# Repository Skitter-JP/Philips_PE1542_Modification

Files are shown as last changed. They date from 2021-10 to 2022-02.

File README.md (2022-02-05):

# Philips PE1542 Modification

This project provides you a 3D model and video with instructions on how to replace the analog meters with digital meters on a Philips PE1542 bench power supply.

The video is available by clicking on the image below.

VIDEO (https://www.youtube.com/embed/GQAOcTNk6Aw)

In the video I have used meters with 3 decimals precision but, the sampling rate on these were incredibly slow. I later switched to meters with 2 decimals precision which were faster. I suspect that these meters contain integrating ADCs, hence the slow updating times.

Click [here](https://www.ebay.com/itm/114450600499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) to view/purchase the meters on eBay.

The mains transformer has 3 outputs. 2 of them are outputting around 30 [Vpp], the last one is at 12[Vpp].

The maximum operating voltage for the replacement meters are 20 [V], this means that for 2 outputs with 30[Vpp] some voltage drop is needed. This was achieved by implementing a [Zener Voltage Regulator](https://www.electronics-tutorials.ws/diode/diode_7.html) circuit after the rectifying capacitor on the two outputs.

The project contains the following folders
1. **3D Model:** An STL file which contains a mount that will fit into the space where the original meters were placed.
2. **Images**: Pictures showcasing the final results of the modification (images might be a bit big to view via GitHub, best to download them)

## 3D Model

The 3D model seen in Google SketchUp

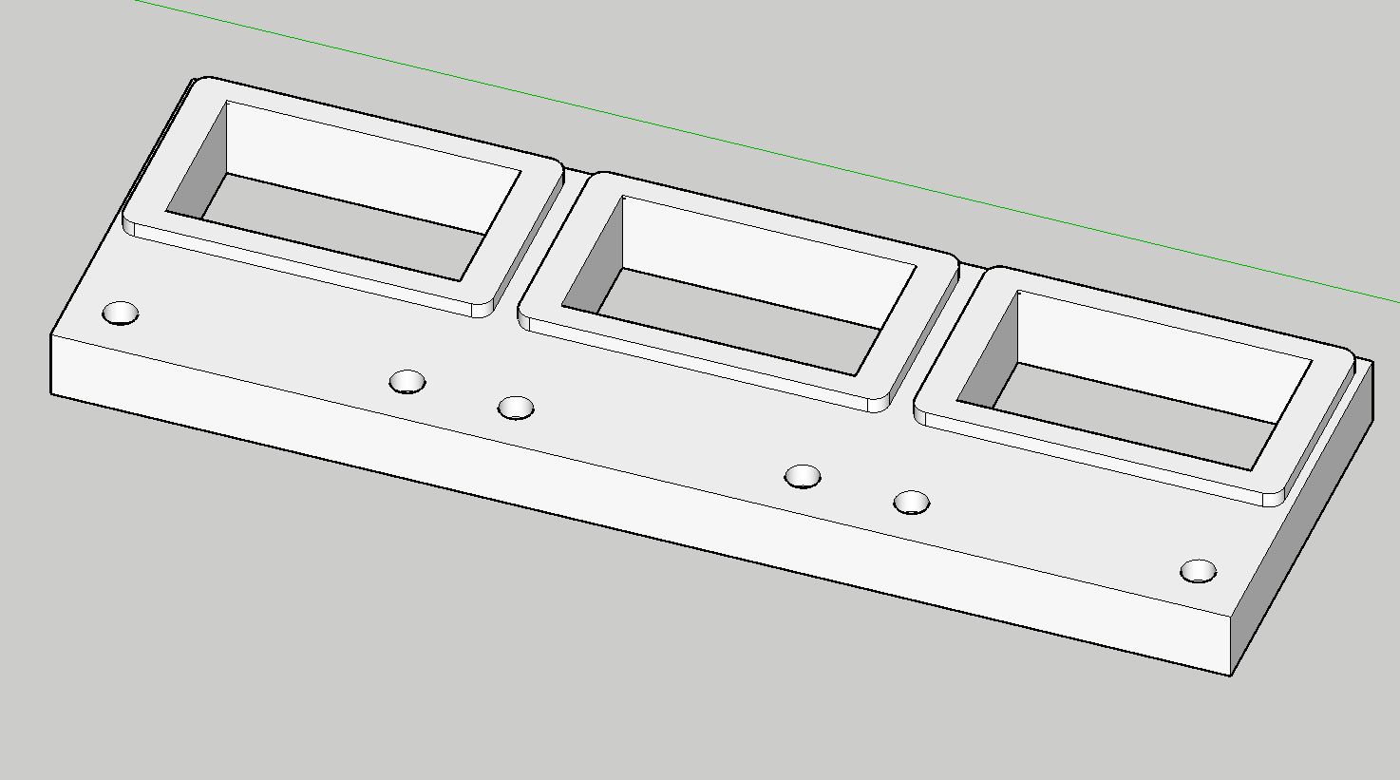
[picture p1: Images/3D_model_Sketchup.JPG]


## 3D Print

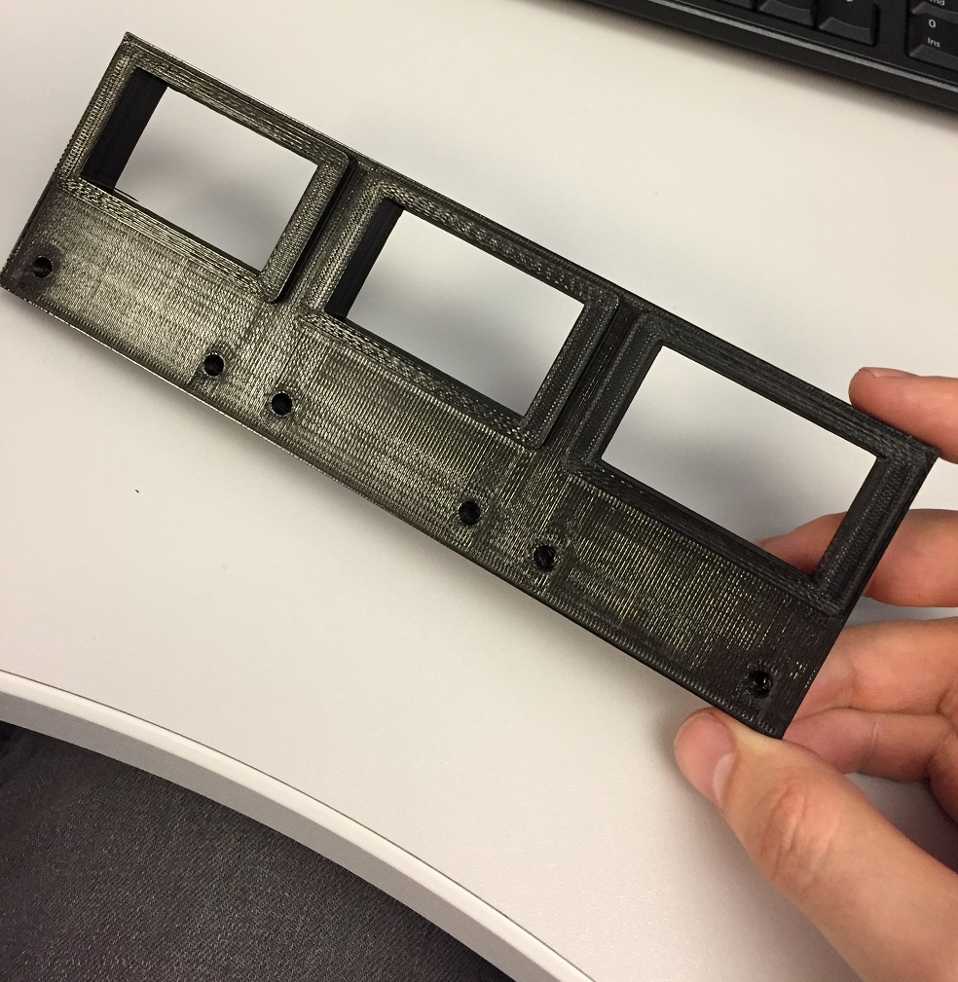
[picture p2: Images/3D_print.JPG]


## Test fitting the 3D print to the faceplate

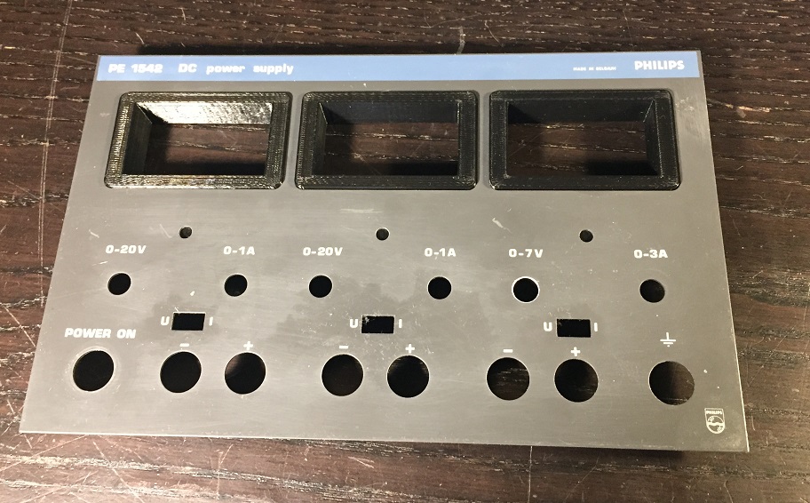
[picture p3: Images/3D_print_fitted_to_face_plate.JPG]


## Test fitting the 3D print into the enclosure

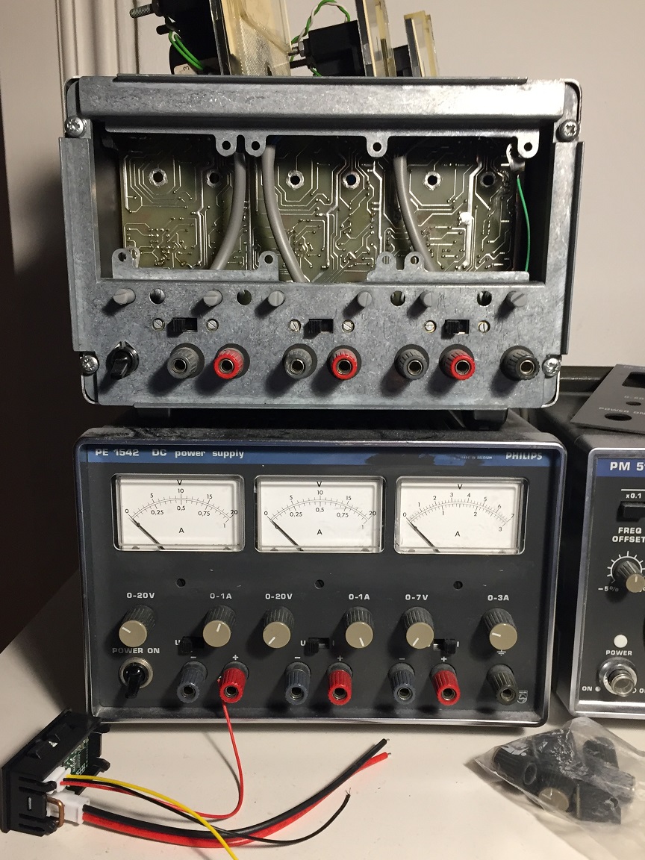
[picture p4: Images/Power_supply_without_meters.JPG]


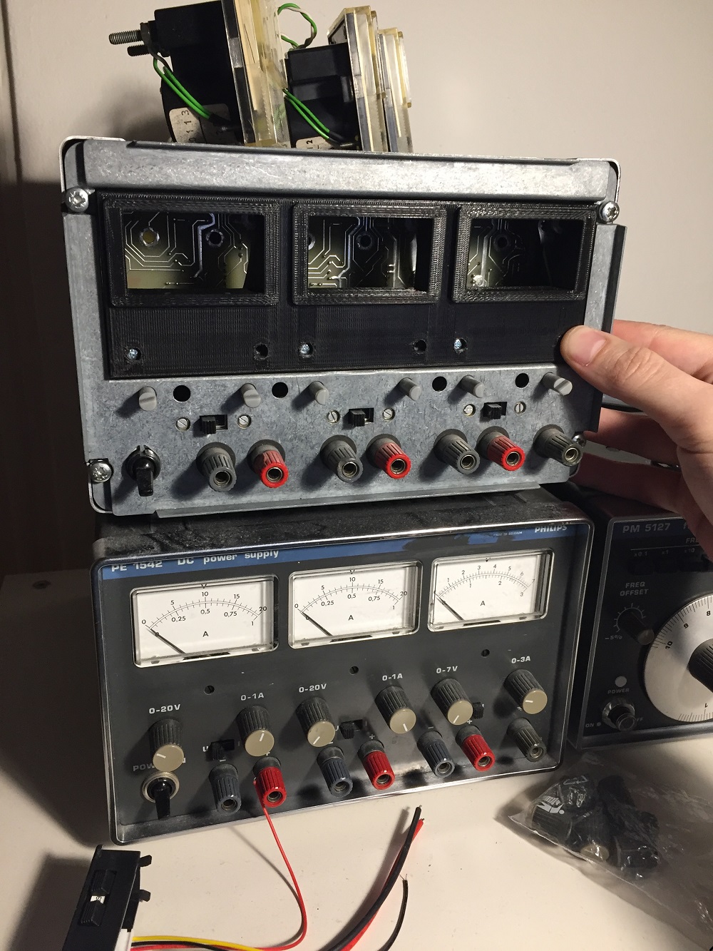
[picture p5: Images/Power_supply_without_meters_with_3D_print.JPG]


## Fitting the Digital Meters to the 3D print

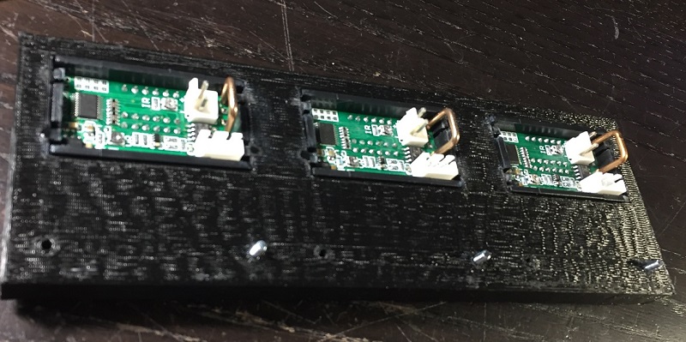
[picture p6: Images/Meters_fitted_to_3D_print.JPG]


## The Zener Regulators

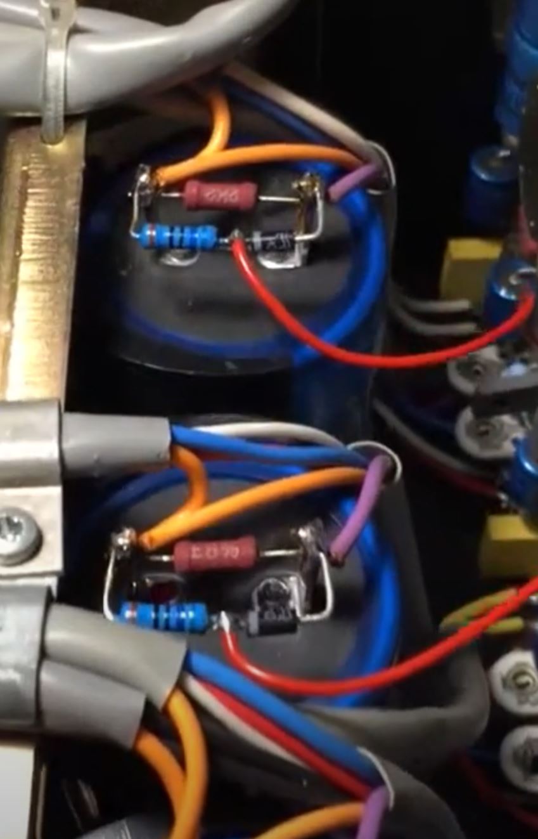
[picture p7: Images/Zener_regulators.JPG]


## Electrical Modifications
Below the electrical modifications can be seen.

In the red circle you can see that the ground connections have been cut, the red and black wires now provide a new current path to the ground, these wires lead to the shunt resistors in the digital meters.

The blue wires are for the voltage sense.

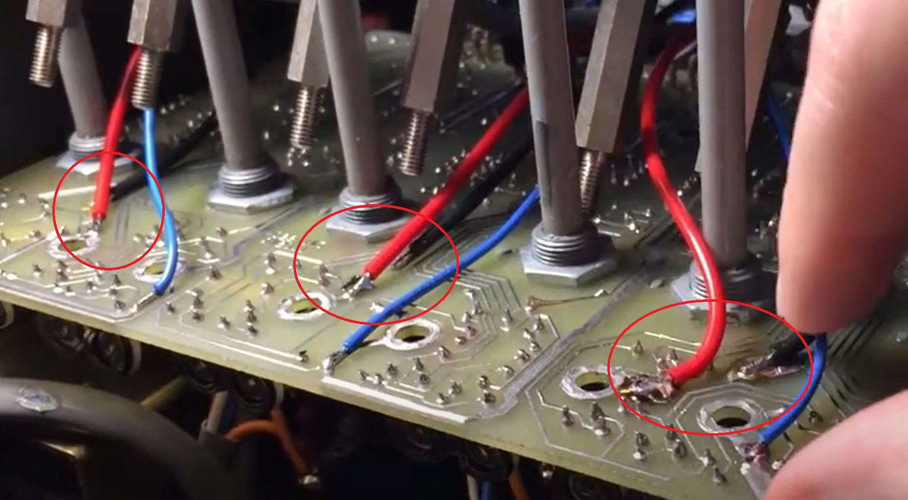
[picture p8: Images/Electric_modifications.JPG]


## Final Result

Here the differences can be seen between the original design and the modified version

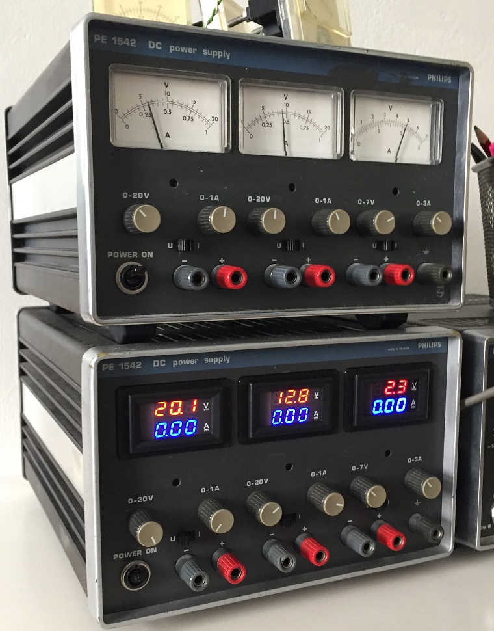
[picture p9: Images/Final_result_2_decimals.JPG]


## Notes
1. The holes in the 3D model are designed for M2.5 screws.
2. No mechanical changes are required other than removing the original meters.
3. Zener Voltage Regulators must be placed on the smoothing Capacitors with 30 [Vpp] (as seen in the video).
4. The Ground tracks going to the output connectors must be cut and the shunt resistor wires need to be placed in between this cut (as seen in the video).
5. The Volt/Current switch will now be inactive, in the future I plan to change this to a on/off button for each output.

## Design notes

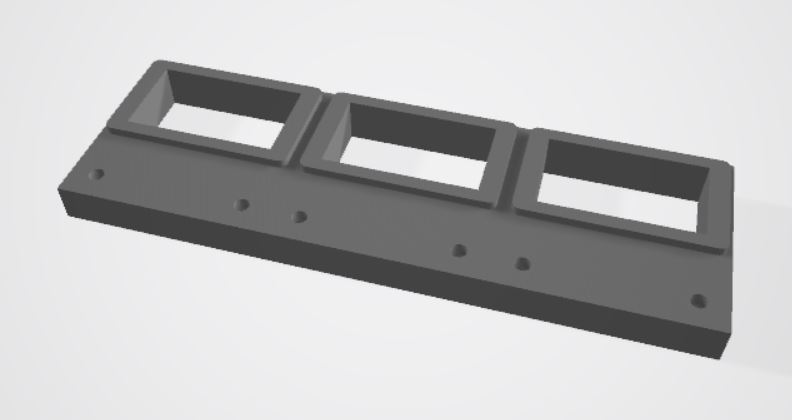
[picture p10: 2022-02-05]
Images/3D_model_1.JPG

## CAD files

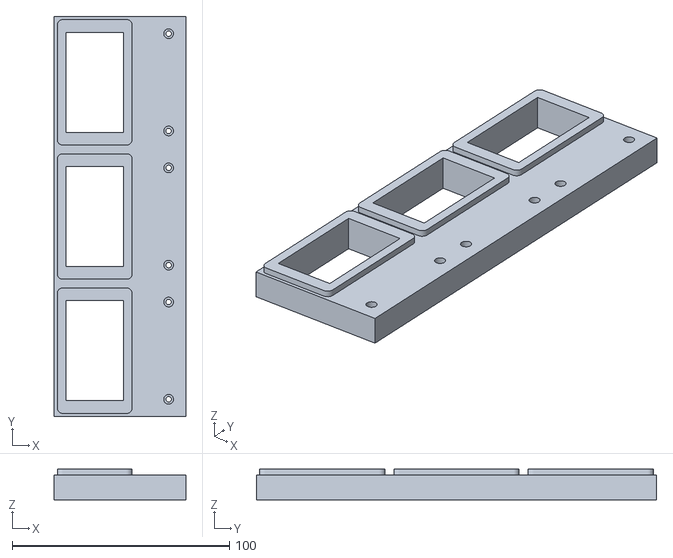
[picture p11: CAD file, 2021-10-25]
3D Model/V1.2_Meters_Larger_M2_Screw hole.stl
60.8 x 184.4 x 14.1

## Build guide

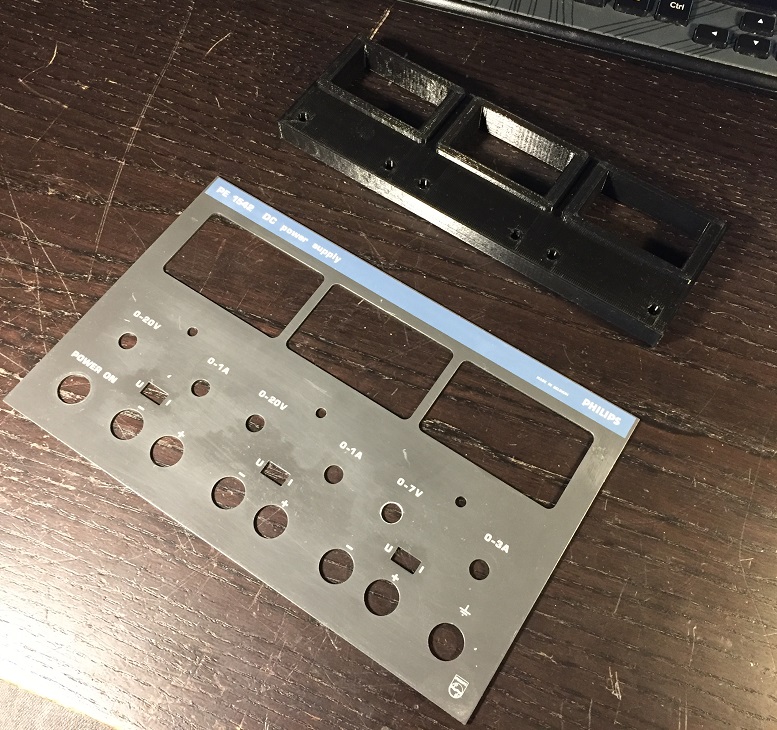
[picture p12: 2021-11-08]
Images/3D_Print_and_Faceplate.JPG

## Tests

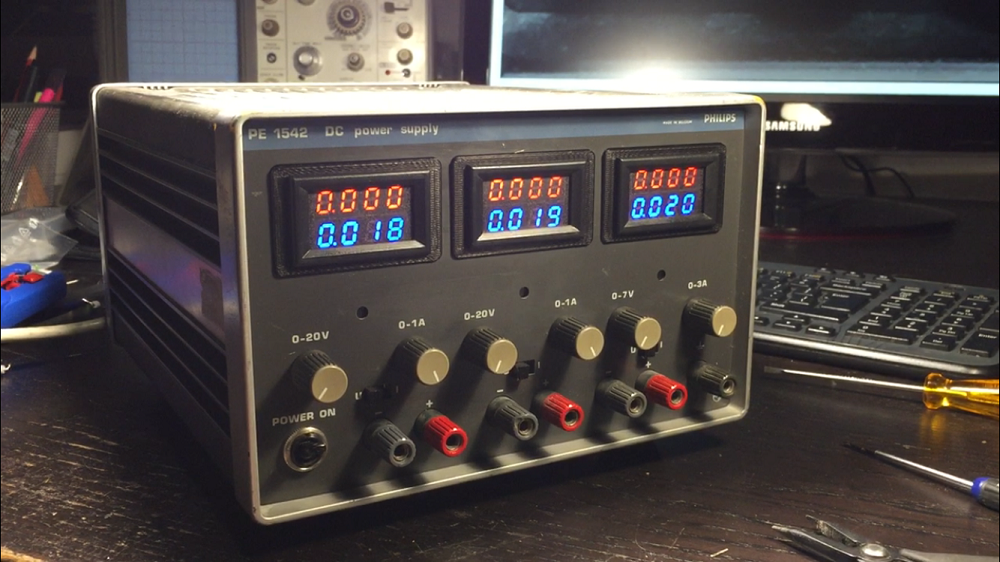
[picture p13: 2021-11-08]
Images/Final_result.PNG
